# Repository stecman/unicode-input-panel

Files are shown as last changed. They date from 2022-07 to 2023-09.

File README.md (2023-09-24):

# UNICODE Input Terminal

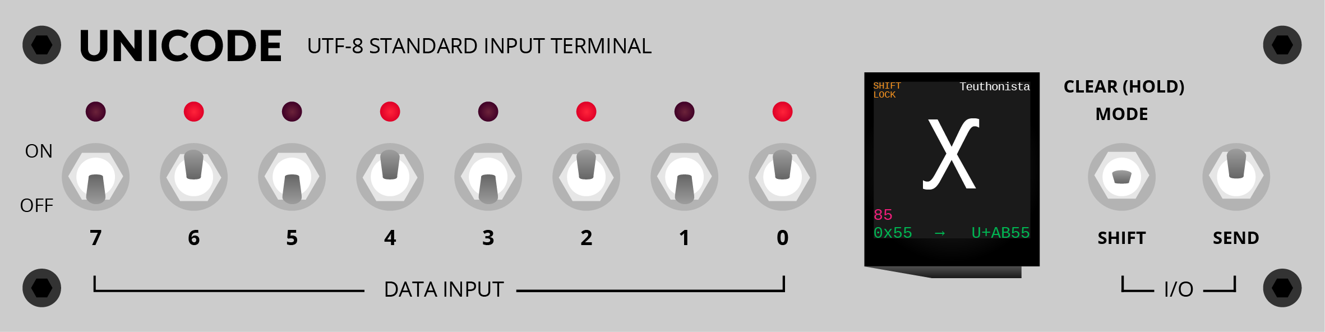
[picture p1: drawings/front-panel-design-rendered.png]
Front panel illustration


Classic binary data entry meets modern Unicode: 144K characters at your
fingertips. A physical user interface to enter any UTF-8 sequence over USB.

A display shows a preview of the selected glyph(s), along with metadata about
the codepoint - all rendered entirely on-device. Tens of megabytes of font
files are required to render glyphs, which are read from an SD card.

See the [Hackaday project page](https://hackaday.io/project/192644-unicode-binary-input-terminal) for more detail about the build.

## Getting started

Parts and wiring can be found in the schematic. The gist is:

 - Raspberry Pi Pico
 - A bunch of switches (8x latching toggle, 1x 3-position momentary, 1x 2-position momentary)
 - ST7789 based display (ideally 280x240, but other resolutions could be made to work)
 - SD card receptacle of some form that can be connected via SPI

A pre-built `.uf2` firmware image can be downloaded from the [releases page]()
if you don't want to build the code yourself.

A package of fonts can be downloaded from the [releases page](). These need to
be placed in a folder called `fonts` at the root of a FAT-formatted SD card. If
you want to bring your own fonts, see the *Preparing fonts* section towards the
end of this readme.

## Developing

You'll need an internet connection for the initial configuration as CMake will
automatically download several dependencies to build from source (FreeType,
libpng, zlib), and some of [Unicode's data tables](https://unicode.org/Public/UNIDATA/).

### Building for desktop

For fast development and debugging, builds can target the host computer. This
renders a virtual screen using SDL2, and doesn't use the Pico SDK at all.

```sh
# Install SDL2 from your package manager
apt-get install libsdl2-dev

# Configure the build
cd firmware
mkdir build
cd build
cmake ../ -DPICO_PLATFORM=host

# Compile
make -j4

# Run the application
./firmware path/to/fonts/
```

### Building for the Pico (command line, Linux)

First:

 - Install `cmake` and `gcc-arm-none-eabi` from your package manager
 - Install the [Raspberry Pi Pico SDK](https://github.com/raspberrypi/pico-sdk)
   and set the `PICO_SDK_PATH` environment variable to point to it.

Then:

```sh
# Configure the build
cd firmware
mkdir build
cd build
cmake ../

# Build firmware image
make -j4
```

This will give you a file `firmware.uf2` in the build directory, which can be
copied to the Pico (when started with the BOOTSEL button held).

### WASM build

The project can also be built to Web Assembly using Emscripten:

```sh
# In a fresh build directory
emcmake cmake -DFONTDIR=path/to/fonts ../
emmake make -j4
```

## Notes

### Preparing fonts

If you want to use fonts other than those in the [prepared bundle](https://github.com/stecman/unicode-input-panel/releases/tag/1.0)
on the device, there are some considerations: FreeType is fairly sparing with
its memory use, but it still requires loading some sections of a font entirely
into memory during initial load/open (`FT_Open_Face`).

- From observation, OTF fonts seem to require more memory to open than TTF fonts.
  The fonts in the prepared bundle were all converted to TTF using [otf2ttf](https://github.com/awesometoolbox/otf2ttf).

- Fonts with many thousands of glyphs like NotoSansJP can be too large to open
  on the Pico, even in TTF format. A couple of these large fonts were split
  into smaller font files with around 500 glyphs each using `pyftsubset`, with
  some logic in `scripts/split-font.py` to keep codepoints used in ligatures
  together to preserve that GSUB table data.

### Changing the embedded UI font

A compact version of Open Sans Regular is built into the firmware for use in the UI,
which only needs basic ASCII glyphs. This is about 5x smaller than the original,
avoiding wasted flash space.

Fonts can be stripped like this using the `pyftsubset` utility from [fonttols](https://github.com/fonttools/fonttools):

```sh
python3 -c 'for i in range(0x20, 0x7D): print("U+%04X" % i)' > ascii-codepoints.txt
pyftsubset SomeFont.ttf --output-file=SomeFont-stripped.ttf --unicodes-file=ascii-codepoints.txt
```

### Debugging memory issues

If you're getting out of memory panics, malloc debugging messages can be
enabled with `-DPICO_DEBUG_MALLOC=1` (prints detail of every allocation to
the serial port).

## Attribution

This project includes copies of:

 - [FatFS SD SPI for Raspberry Pi Pico](https://github.com/carlk3/no-OS-FatFS-SD-SPI-RPi-Pico),
   which contains [FatFS](http://elm-chan.org/fsw/ff/00index_e.html). This is included as
   source in the repository because it need slight tweaks to build correctly.

 - A stripped down version of the [OpenSans](https://github.com/googlefonts/opensans)
   Regular font is included in this repository: Copyright 2020 The Open Sans Project Authors

 - The releases page has an archive with redistribution of the Noto Regular fonts
   ([noto-fonts](https://github.com/googlefonts/noto-fonts/) and
   [noto-emoji](https://github.com/googlefonts/noto-emoji)): Copyright 2018 The Noto Project Authors

The respective licenses for these are included with the associated files.

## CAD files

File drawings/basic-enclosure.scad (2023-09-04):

$fn = 90;

// Panel dimensions (adjust as needed)
a = 20;
h = 50;
l = 205;
id = 34;
wall = 2.2;

screw_radius = (2.95/2);
hole_offset_w = 7.75 + screw_radius;

hole_offset_top = 5.5 + screw_radius;
hole_offset_bot = 5 + screw_radius;

module enclosure(x,y,z,a=20) {
	difference() {
		// Box
		rotate([-a, 0, 0]) cube([x, y, z]);
		
		// Flatten bottom
		translate([-x/2, -y/2, -z]) cube([x*2, y*2, z]);
	}
}

// Enclosure
union() {
	// Main box shell
	difference() {
		enclosure(l, id, h);
		translate([wall, -wall, wall]) enclosure(l - wall*2, id, h - (wall*2));
	}
	
	// Screw posts
	for (x = [5, l - 5]) {
		for (y = [5, h - 5]) {
			intersection() {
				// Cut any extensions outside of the panel area
				enclosure(l, id, h);
				rotate([90-20, 0, 0]) translate([x, y, -6]) cylinder(h=id, d=20);
			}
		}
	}

	// Middle rib
	difference() {
		intersection() {
			// Cut any extensions outside of the panel area
			enclosure(l, id, h);
			translate([l/2 -5 , 0, 0]) cube([10, 100, h]);
		}
		
		translate([0, -wall, wall*2]) enclosure(l, id-wall, h - wall*4);
	}
}

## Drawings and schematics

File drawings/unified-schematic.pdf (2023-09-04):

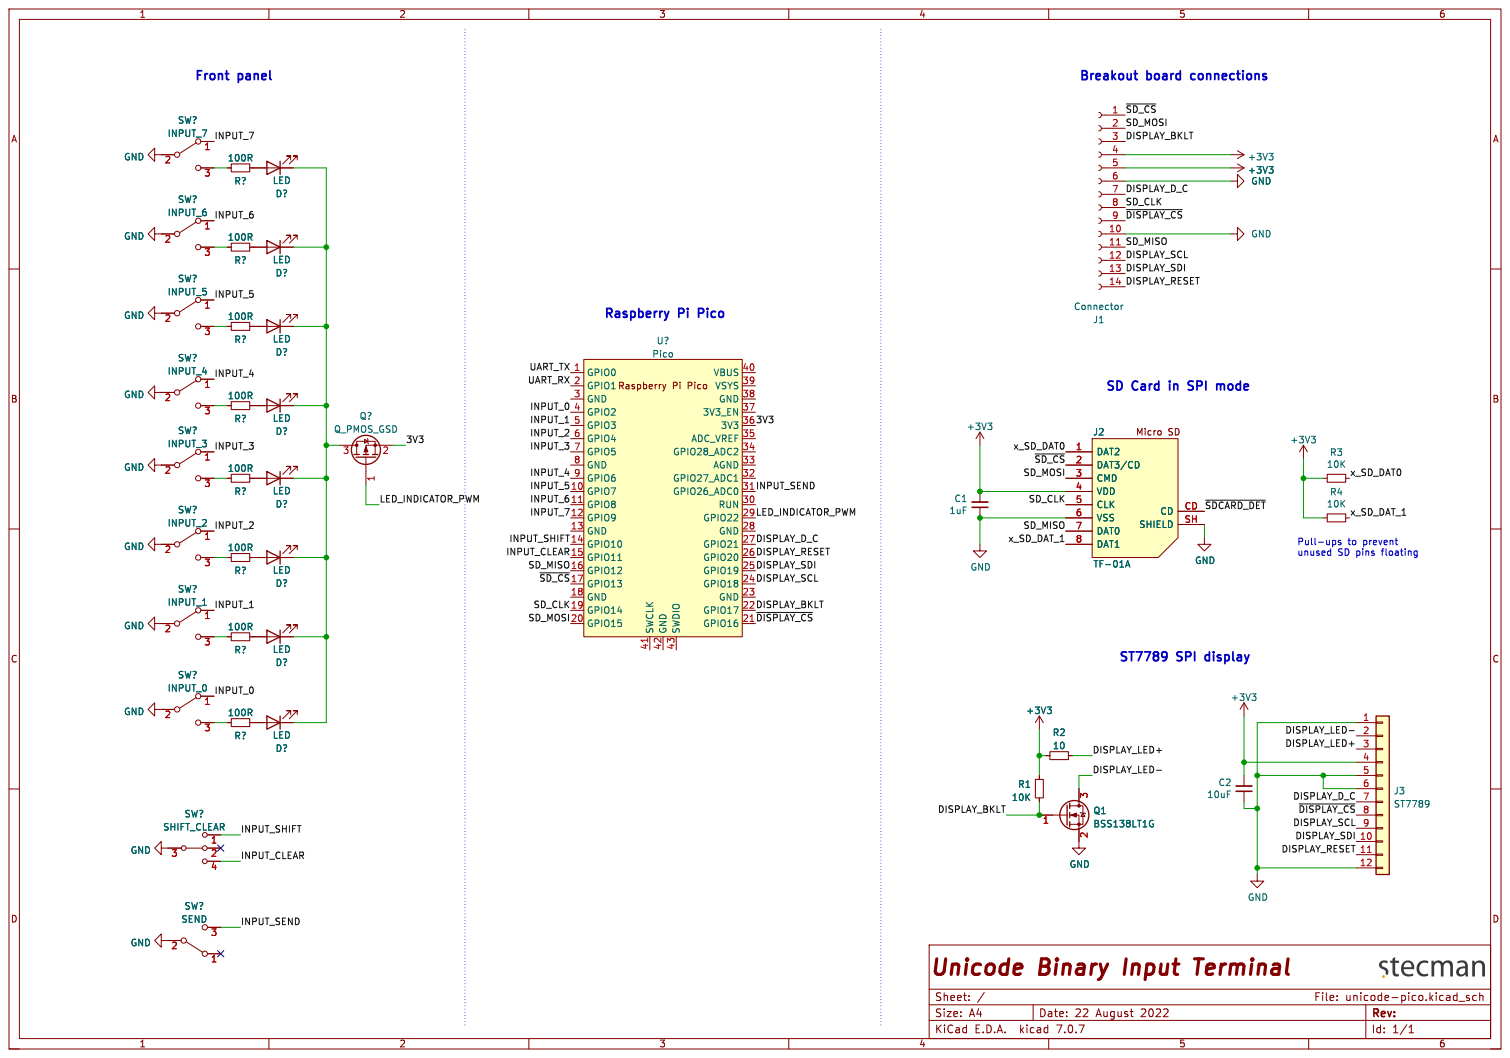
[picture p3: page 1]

SD Card in SPI mode

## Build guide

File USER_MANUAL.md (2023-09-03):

# UNICODE UTF-8 STANDARD INPUT TERMINAL

This user manual describes operation of your new, state of the art, UTF-8
binary input terminal. While this is a relatively simple data entry device,
several functions are not necessarily obvious, so all users are encouraged
to read this short manual.

## Power-up

When the device is turned on, it scans all fonts installed in the `fonts/`
directory on the SD card for fast access later. The Unicode logo is displayed
on screen while this scan is in progress, which takes around 30 seconds with
the standard font package. The colouring of the logo represents the progress
of this scan. When the logo is fully coloured, all fonts have been processed
and the device is ready to use.

The USB interface of the device will not activate until after this initial
loading is complete.

## Data Entry

In all modes:

 - The most significant byte is selected first, then right-shifted by briefly
   engaging the SHIFT switch. For example, to make the value `0x1234` you first
   select `0x12` on the DATA INPUT switches, press the SHIFT switch momentarily,
   then select `0x34` on the DATA INPUT switches: your buffer now has the desired
   value and can be sent.

 - Pressing the SEND switch will output the current buffer to the host computer
   system. The buffer will be reset to the current DATA INPUT byte selection after
   sending unless shift-lock is engaged.

 - Holding SHIFT enables shift-lock. Shift-lock retains the most significant bytes
   of the buffer across SEND operations, allowing multiple codepoints in the same
   range to be entered rapidly. For example with shift lock enabled, you can enter
   `0x1F40D`, press send, then simply flip DATA INPUT bit 6 and press send again
   for `0x1F44D`.

 - Pressing the MODE switch momentarily will cycle between the input and view modes
   described below. The buffer and shift-lock will be retained while switching modes.

 - Holding CLEAR resets the buffer to the current DATA INPUT selection and disables
   shift-lock. The selected mode remains active.

## Modes

### Codepoint Mode (HEX, DEC)

 - Entry of a codepoint value via DATA INPUT and SHIFT

 - Codepoint value is displayed in hexadecimal (HEX) or decimal (DEC), centred
   at the bottom of the screen.

 - The corresponding glyph is rendered if the codepoint is found in any of the
   available fonts.

 - Unicode block and codepoint names are displayed at the top of the screen
   when codepoint is valid.

### UTF-8 Mode (UTF-8)

 - Entry of a [1-4 byte UTF-8 sequence](https://en.wikipedia.org/wiki/UTF-8#Encoding)
   via DATA INPUT and SHIFT

 - If an invalid encoding is entered, binary literals will be shown with
   problematic bits highlighted in red.

 - The SHIFT operation is automatically limited to the encoded sequence length.

 - A glyph will be rendered when a valid UTF-8 sequence is entered, if found in
   the available fonts.

 - Unicode block and codepoint names are displayed at the top of the screen
   when codepoint is valid.

Changing to this mode will show the UTF-8 encoding of the codepoint selected in
the previous mode. The low byte may not match the DATA INPUT switches at this
time. When the DATA INPUT changes, the low byte will be updated.

### Numeric / Programmer Mode (LITERAL)

 - Always shows a large hexadecimal representation of the input buffer

 - Pressing SEND writes the literal hex value like "0xF1"

## Notes

### Glyph display

Glyphs are always drawn so their visible components are centred on screen,
rather than using a fixed baseline. This means glyphs lose some positional
information, which is not technically accurate, but provides consistent
positioning for glyphs of all shapes and sizes, regardless of how their
script handles baselines.

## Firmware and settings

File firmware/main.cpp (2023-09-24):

#include "st7789.h"
#include "ui/main_ui.hh"
#include "usb.h"

// Pico SDK
#include "hardware/gpio.h"
#include "hardware/pwm.h"
#include "hardware/spi.h"
#include "hardware/uart.h"
#include "pico/stdio_usb.h"
#include "pico/stdlib.h"
#include "pico/time.h"

#include <stdio.h>

#define PIN_UART_DEBUG_TX 0
#define PIN_DISP_CS 16
#define PIN_DISP_BKLGHT 17
#define PIN_DISP_SPI_SCK 18
#define PIN_DISP_SPI_TX 19
#define PIN_DISP_RESET 20
#define PIN_DISP_DC 21

#define PIN_LED_PWM 22
#define PIN_SWITCH_SHIFT 10
#define PIN_SWITCH_MODECLEAR 11
#define PIN_SWITCH_SEND 26

struct st7789_config display_config ={
	.spi = spi0,
    .gpio_din = PIN_DISP_SPI_TX,
    .gpio_clk = PIN_DISP_SPI_SCK,
    .gpio_cs = PIN_DISP_CS,
    .gpio_dc = PIN_DISP_DC,
    .gpio_rst = PIN_DISP_RESET,
    .gpio_bl = PIN_DISP_BKLGHT
};

static volatile bool needs_render = true;
struct repeating_timer render_timer;

bool render_timer_callback(struct repeating_timer *t) {
    needs_render = true;
    return true;
}

/**
 * Get the byte selected on the data input switch panel
 */
uint8_t get_input_byte()
{
    return ((uint8_t) (gpio_get_all() >> 2));
}

/**
 * Logic for short and long presses on an active-low GPIO input
 */
class UserInput
{
public:
    UserInput(uint32_t gpio) : m_gpio(gpio) {}

    void update()
    {
        const bool pressed = gpio_get(m_gpio) == 0;

        if (pressed != m_pressed) {
            m_pressed = pressed;

            if (m_pressed) {
                m_handled = false;
                m_long_press = make_timeout_time_ms(400);
            } else {
                m_long_press = nil_time;
            }
        }
    }

    // Read and clear the pressed state
    inline bool pressed()
    {
        if (!m_handled && m_pressed) {
            m_handled = true;
            return true;
        }

        return false;
    }

    // Read and clear the long press state
    bool was_long_pressed()
    {
        if (!m_handled && m_long_press != nil_time && get_absolute_time() > m_long_press) {
            m_long_press = 0;
            m_handled = true;
            return true;
        }

        return false;
    }

    // Read and clear the short press state
    bool was_short_pressed()
    {
        if (!m_handled && m_long_press == nil_time) {
            m_handled = true;
            return true;
        }

        return false;
    }

private:
    uint32_t m_gpio;

    // Time to trigger a long press, or zero if not pressed
    absolute_time_t m_long_press = nil_time;
    bool m_pressed = false;
    bool m_handled = true;
};


// Use keycode conversion table provided by the Pico SDK
static constexpr size_t kAsciiToKeycodeLength = 128;
static constexpr uint8_t kAsciiToKeycode[kAsciiToKeycodeLength][2] = { HID_ASCII_TO_KEYCODE };

class CodepointSender
{
public:
    void send(uint32_t codepoint)
    {
        constexpr uint8_t indexShift = 0;
        constexpr uint8_t indexKeycode = 1;

        // TODO: handle send send buffer full

        // Send a single key if the codepoint is valid ASCII
        // Note this will be incompatible with non-US keyboard layouts
        if (codepoint < kAsciiToKeycodeLength) {
            uint8_t keycode = kAsciiToKeycode[codepoint][indexKeycode];
            if (keycode != 0) {
                uint8_t modifiers = kAsciiToKeycode[codepoint][indexShift] ? KEYBOARD_MODIFIER_LEFTSHIFT : 0;
                m_key_queue[m_queue_size++] = KeyPress(keycode, modifiers);
                start_sending();
                return;
            }
        }

        // Convert to a sequence of key presses for a specific operating system
        // TODO: Currently this only supports Linux Ctrl+Shift+U sequence entry
        char _buf[12];
        char* str = (char*) &_buf;
        sprintf(str, "%X", codepoint);

        // Start unicode hex entry (Linux desktop)
        m_key_queue[m_queue_size++] = KeyPress(HID_KEY_U, KEYBOARD_MODIFIER_LEFTCTRL | KEYBOARD_MODIFIER_LEFTSHIFT);

        while (*str != '\0') {
            uint8_t keycode = kAsciiToKeycode[*str][indexKeycode];
            m_key_queue[m_queue_size++] = KeyPress(keycode);
            str++;
        }

        // Finish sequence with enter
        m_key_queue[m_queue_size++] = KeyPress(HID_KEY_ENTER);

        start_sending();
    }

    // Returns true when sending has completed
    bool update()
    {
        if (m_waiting && !usb_last_report_sent()) {
            // Waiting between reports
            return false;
        }

        m_waiting = false;

        if (m_needs_release) {
            // Send a report with the previous key press released
            send_release();
            return false;
        }

        if (m_queue_size == 0) {
            // Stop sending
            return true;
        }

        // Send next key press, or reset
        if (m_index < m_queue_size) {
            auto& press = m_key_queue[m_index++];
            send_key(press.keycode, press.modifiers);

        } else {
            // No more keys to send
            m_queue_size = 0;
            m_index = 0;

            // Stop sending
            return true;
        }

        return false;
    }

private:
    void start_sending()
    {
        // Start sending keys if it's not running yet
        if (m_send_timer.alarm_id == 0) {
            add_repeating_timer_ms(1, key_send_callback, this, &m_send_timer);
            update();
        }
    }

    static bool key_send_callback(struct repeating_timer *t)
    {
        auto* sender = reinterpret_cast<CodepointSender*>(t->user_data);
        return !sender->update(); // Update and cancel if no more to send
    }

    void send_key(uint8_t keycode, uint8_t modifiers = 0)
    {
        m_keymap[0] = keycode;
        usb_set_key_report(m_keymap, modifiers);

        m_needs_release = true;
        m_waiting = true;
    }

    void send_release()
    {
        m_keymap[0] = 0;
        usb_set_key_report(m_keymap, 0);
        m_needs_release = false;
        m_waiting = true;
    }

    struct KeyPress {
        KeyPress() : keycode(0), modifiers(0) {}
        KeyPress(uint8_t keycode) : keycode(keycode), modifiers(0) {}
        KeyPress(uint8_t keycode, uint8_t modifiers) : keycode(keycode), modifiers(modifiers) {}

        uint8_t keycode;
        uint8_t modifiers;
    };

    struct repeating_timer m_send_timer;

    uint32_t m_index = 0;
    uint32_t m_queue_size = 0;
    KeyPress m_key_queue[16];
    bool m_waiting = false;
    bool m_needs_release = false;

    uint8_t m_keymap[6]= {0, 0, 0, 0, 0, 0};
};


bool background_usb_poll(struct repeating_timer *t)
{
    usb_poll();
    return true;
}

int main()
{
    static MainUI app;
    static CodepointSender sender;

    usb_init();
    stdio_usb_init();

    // Run USB polling from an interrupt as the main loop slows down when rendering
    static struct repeating_timer usb_timer;
    add_repeating_timer_ms(5, background_usb_poll, NULL, &usb_timer);

    printf("\n\nDevice has reset\n");

	// GPIOs 0-11 as inputs with pull-up
	// (Looping as there's no mask function for direction)
	for (unsigned int pin = 1; pin <= 11; pin++) {
		gpio_init(pin);
		gpio_pull_up(pin);
		gpio_set_dir(pin, GPIO_IN);
	}

    // Send switch input is somewhere else
    gpio_init(PIN_SWITCH_SEND);
    gpio_pull_up(PIN_SWITCH_SEND);
    gpio_set_dir(PIN_SWITCH_SEND, GPIO_IN);

    // Configure switch LED PWM as off for loading
	{
        gpio_init(PIN_LED_PWM);
        gpio_put(PIN_LED_PWM, 1);
        gpio_set_dir(PIN_LED_PWM, GPIO_OUT);
        gpio_set_drive_strength(PIN_LED_PWM, GPIO_DRIVE_STRENGTH_12MA);
	}

	// Configure backlight PWM
    // This is just left on max brightness for now. The intention is to dim when in
	{
        gpio_init(PIN_DISP_BKLGHT);
        gpio_put(PIN_DISP_BKLGHT, 0);
        gpio_set_dir(PIN_DISP_BKLGHT, GPIO_OUT);

		gpio_set_function(PIN_DISP_BKLGHT, GPIO_FUNC_PWM);

	    const uint32_t slice_num = pwm_gpio_to_slice_num(PIN_DISP_BKLGHT);
	    pwm_set_wrap(slice_num, 1024);
	    pwm_set_chan_level(slice_num, PWM_CHAN_A, 512);
	    pwm_set_enabled(slice_num, true);

        pwm_set_gpio_level(PIN_DISP_BKLGHT, 1024);
    }

	// Select pins to use for SPI0
	gpio_set_function(PIN_DISP_SPI_SCK, GPIO_FUNC_SPI);
	gpio_set_function(PIN_DISP_SPI_TX, GPIO_FUNC_SPI);

	// Enable SPI0 for screen
	spi_init(spi0, 32e6);

    const uint32_t LED_PIN = PICO_DEFAULT_LED_PIN;
    gpio_init(LED_PIN);
    gpio_set_dir(LED_PIN, GPIO_OUT);


    // Set up and blank display
    st7789_init(&display_config, DISPLAY_WIDTH, DISPLAY_HEIGHT);

    // The particular screen I have has Y 0-20 outside of the display by default
    // Scroll so 0,0 in memory is actually rendered in the top-left corner
    st7789_vertical_scroll(300);

    // Start the application (blocking until loaded)
    app.load("fonts");

    // Turn on data input LEDs (inverted as this drives a P-channel mosfet)
    {
        gpio_set_function(PIN_LED_PWM, GPIO_FUNC_PWM);

	    const uint32_t slice_num = pwm_gpio_to_slice_num(PIN_LED_PWM);
	    pwm_set_wrap(slice_num, 1024);
	    pwm_set_chan_level(slice_num, PWM_CHAN_A, 512);
	    pwm_set_enabled(slice_num, true);

        // Very dim as the 100 Ohm resistors I'm using are a bit blinding
        pwm_set_gpio_level(PIN_LED_PWM, 1022);
    }

    uint8_t last_input = get_input_byte();
    app.set_low_byte(last_input);

    add_repeating_timer_ms(30, render_timer_callback, NULL, &render_timer);

    UserInput shift_switch(PIN_SWITCH_SHIFT);
    UserInput modeclear_switch(PIN_SWITCH_MODECLEAR);
    UserInput send_switch(PIN_SWITCH_SEND);

    while (true) {
        if (needs_render) {
            needs_render = false;

            // Handle inputs once per frame for now as it's easy
            const uint8_t input = get_input_byte();
            if (input != last_input) {
                last_input = input;
                app.set_low_byte(input);
            }

            shift_switch.update();
            modeclear_switch.update();
            send_switch.update();

            if (shift_switch.was_long_pressed()) {
                app.toggle_shift_lock();
            } else if (shift_switch.was_short_pressed()) {
                app.shift();
            }

            if (modeclear_switch.was_long_pressed()) {
                app.reset();
            } else if (modeclear_switch.was_short_pressed()) {
                app.goto_next_mode(input);
            }

            if (send_switch.pressed()) {
                for (uint32_t codepoint : app.get_codepoints()) {
                    sender.send(codepoint);
                }
            }

            app.tick();
        }
    }
}

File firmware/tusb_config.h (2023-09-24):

/*
 * The MIT License (MIT)
 *
 * Copyright (c) 2019 Ha Thach (tinyusb.org)
 *
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
 */

#ifndef _TUSB_CONFIG_H_
#define _TUSB_CONFIG_H_

#ifdef __cplusplus
 extern "C" {
#endif

//--------------------------------------------------------------------
// COMMON CONFIGURATION
//--------------------------------------------------------------------

// defined by board.mk
#ifndef CFG_TUSB_MCU
  #error CFG_TUSB_MCU must be defined
#endif

// RHPort number used for device can be defined by board.mk, default to port 0
#ifndef BOARD_DEVICE_RHPORT_NUM
  #define BOARD_DEVICE_RHPORT_NUM     0
#endif

// RHPort max operational speed can defined by board.mk
// Default to Highspeed for MCU with internal HighSpeed PHY (can be port specific), otherwise FullSpeed
#ifndef BOARD_DEVICE_RHPORT_SPEED
  #if (CFG_TUSB_MCU == OPT_MCU_LPC18XX || CFG_TUSB_MCU == OPT_MCU_LPC43XX || CFG_TUSB_MCU == OPT_MCU_MIMXRT10XX || \
       CFG_TUSB_MCU == OPT_MCU_NUC505  || CFG_TUSB_MCU == OPT_MCU_CXD56 || CFG_TUSB_MCU == OPT_MCU_SAMX7X)
    #define BOARD_DEVICE_RHPORT_SPEED   OPT_MODE_HIGH_SPEED
  #else
    #define BOARD_DEVICE_RHPORT_SPEED   OPT_MODE_FULL_SPEED
  #endif
#endif

// Device mode with rhport and speed defined by board.mk
#if   BOARD_DEVICE_RHPORT_NUM == 0
  #define CFG_TUSB_RHPORT0_MODE     (OPT_MODE_DEVICE | BOARD_DEVICE_RHPORT_SPEED)
#elif BOARD_DEVICE_RHPORT_NUM == 1
  #define CFG_TUSB_RHPORT1_MODE     (OPT_MODE_DEVICE | BOARD_DEVICE_RHPORT_SPEED)
#else
  #error "Incorrect RHPort configuration"
#endif

#ifndef CFG_TUSB_OS
#define CFG_TUSB_OS               OPT_OS_NONE
#endif

// CFG_TUSB_DEBUG is defined by compiler in DEBUG build
// #define CFG_TUSB_DEBUG           0

/* USB DMA on some MCUs can only access a specific SRAM region with restriction on alignment.
 * Tinyusb use follows macros to declare transferring memory so that they can be put
 * into those specific section.
 * e.g
 * - CFG_TUSB_MEM SECTION : __attribute__ (( section(".usb_ram") ))
 * - CFG_TUSB_MEM_ALIGN   : __attribute__ ((aligned(4)))
 */
#ifndef CFG_TUSB_MEM_SECTION
#define CFG_TUSB_MEM_SECTION
#endif

#ifndef CFG_TUSB_MEM_ALIGN
#define CFG_TUSB_MEM_ALIGN          __attribute__ ((aligned(4)))
#endif

//--------------------------------------------------------------------
// DEVICE CONFIGURATION
//--------------------------------------------------------------------

#ifndef CFG_TUD_ENDPOINT0_SIZE
#define CFG_TUD_ENDPOINT0_SIZE    64
#endif

//------------- CLASS -------------//
#define CFG_TUD_HID               1
#define CFG_TUD_CDC               1
#define CFG_TUD_MSC               0
#define CFG_TUD_MIDI              0
#define CFG_TUD_VENDOR            0

// HID buffer size Should be sufficient to hold ID (if any) + Data
#define CFG_TUD_HID_EP_BUFSIZE    16

// CDC FIFO size of TX and RX
#define CFG_TUD_CDC_RX_BUFSIZE   (TUD_OPT_HIGH_SPEED ? 512 : 64)
#define CFG_TUD_CDC_TX_BUFSIZE   (TUD_OPT_HIGH_SPEED ? 512 : 64)

// CDC Endpoint transfer buffer size, more is faster
#define CFG_TUD_CDC_EP_BUFSIZE   (TUD_OPT_HIGH_SPEED ? 512 : 64)

#ifdef __cplusplus
 }
#endif

#endif /* _TUSB_CONFIG_H_ */

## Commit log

2022-06-29 Front-panel mock-up with drill hits
2022-07-31 Remove harfbuzz as it's not capable of running on micro memory systems
    Harfbuzz's FreeType integration is written to load the entire font into
    memory. I wanted Harfbuzz as a drop-in solution for substitution of
    emoji sequences, which are stored in the 9MB NotoColorEmoji font
    currently. This won't work without significant modification to Harfbuzz,
    so I'll need a different solution to achieve ZWJ sequences.
    Looks like we'll need to look up the GSUB table on our own to do this 🕶
2022-09-25 Add SDL host keyboard controls equivalent to hardware switches
2022-11-26 Fix host mode main thread slamming CPU unnecessarily hard
    The main loop was running at 100% CPU as it was going around as fast
    as possible. This adds a brief delay so the process can sleep.
2022-11-26 Force display backlight on (will configure PWM brightness later)
2022-12-11 Draw "invalid codepoint" as a banner instead of a special case
    For consistency, this keeps the title area as the the codepoint metadata.
    The current hex value is displayed the same as other non-renderable values.
2022-12-11 Use a shared font face between UIFontPen instances to avoid repeated reloading
    Loading memory fonts is fast, but it's still a waste of cycles to do it
    repeatedly in the same render call. API-wise this isn't great as it adds
    a number of places where bugs can creep in, and limits how the UIFontPen
    class can be used. These limitations are acceptable with the way it's
    currently being used, and the cost of loading fonts.
2022-12-11 Fix long press on host not properly cleared on release
    If the key was pressed repeatedly, the timer still running for long press
    could fire when the key was down and think this was a long press incorrectly.
2022-12-11 Fix fill_window_colour implemented as RGB rather than BGR for the hardware
    [st7789.c]
2022-12-11 Add simple mode switch for dec/hex display, plus shift lock indicator
    I want to add other input modes, but this is a "good enough" polish for
    now to document this project for others.
2022-12-11 Connect hardware inputs to application to run on device
2022-12-13 Don't link tinyusb when building for host
    This was put in the wrong place, which only worked building for the device.
2022-12-23 Separate codepoint input/view mode from MainUI class, allowing multiple views
    "View" is not really the right term as CodepointView is essentially a
    mini application that's plugged into the the human interface of the
    device. I was considering making literally making views around a
    common buffer stored in MainUI, but it's not straight forward since:
    - Codepoint selection mode needs to work on 32-bit codepoint values
    - UTF-8 direct input mode needs to work on a uint8_t array
    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
2022-12-27 Add view allowing interaction with UTF-8 encoding
    To keep mode switches consistent, the selected codepoint is automatically
    converted to and from UTF-8 when entering and leaving this UTF-8 view.
    This mode isn't really practical for entry as it just makes things harder
    for no reason, but it's interesting to explore how UTF-8 encoding works.
2022-12-27 Add hex literal view to show large print hex and send "0x..." sequences
2022-12-27 Hold shift-lock when changing through all views
    This is a bit messy as there's no shared state for the views to query
    about shift lock, shared buffer, etc, so the views all independently
    need to keep track of shift lock in addition to MainUI.
2023-02-05 Add basic support for building a WASM target for web with Emscripten
    This required fixing a number of build compilation incompatibilities
    between different platforms:
    - Replaced use of dynamic_cast as the device builds have RTTI disabled
    - Replaced all use of the `uint` type with an appropriate type as `uint`
    isn't supported by Emscripten
    - Added flexibility for where fonts are read from to support host and
    wasm builds with fonts coming from different places
    - Moved asset embeds to their own include so they can be loaded from
    file by Emscripten, since it doesn't support binary embeds in the
    same way as host and device builds
    - Removed Pico SDK entirely when building with Emscrip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
    [main.cpp]
2023-02-08 Separate font load from MainUI construction
    This is still a blocking process. The intention is to allow it to be
    cooperative for running in a browser, though the browser loading
    requirements are quite different to device/host, so this might be moot.
2023-02-09 Update manual to more accurately describe device behaviour
2023-09-01 Remove requirement for Pico SDK for non-Pico targets
    Host and WASM builds don't use the Pico SDK, but it was still required
    to configure. I've removed this so the project is easier to boot up for
    new-comers who just want to play with it.
2023-09-04 Add PDF copy of schematic
    I plan to add the KiCAD source files, but that needs a bit of clean up
    first. This is an all-in-one schematic I hacked together for publishing.
2023-09-04 Add OpenSCAD design file for enclosure
    This was something I slapped together, but including for anyone
    interested.
    [basic-enclosure.scad]
2023-09-05 Remove errant bracket in readme
2023-09-24 Fix incorrect type in SD card library
    Failed to compile with arm-none-eabi-gcc 13.2
    [sd_spi.c]
2023-09-24 Fix compile errors against the current Pico SDK
    [main.cpp, st7789.c]
2023-09-24 Add USB serial support to standard build
    The UART ports are difficult to access now they're inside an enclosure.
    This adds the descriptors required for the Pico SDK's stdio_usb_init to
    work in cooperation with an existing custom custom USB endpoint.
2023-09-24 Fix keys not sending in literal mode
    Not sure if I broke this at some point, or if I just never tested it on
    the hardware. Sending from literal mode was sending a single Ctrl-Shift-U
    and enter, rather than one per character to send.
    I've overhauled this so it's more flexible to support other OS sequence
    implementations in future.
    [main.cpp]
2023-09-24 Decouple key press sending from main loop for consistent performance
    This switches to a repeating timer instead of polling the send loop as
    it's simpler, faster and doesn't cause jittery key rate when the data
    input is changed during send
    [main.cpp]
2023-09-24 Always run USB polling from an interrupt to avoid lag from rendering
    Sending while text was scrolling was running very slowly
    [main.cpp]
